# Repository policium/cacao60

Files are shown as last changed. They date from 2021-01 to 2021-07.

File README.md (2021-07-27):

# Cacao60%
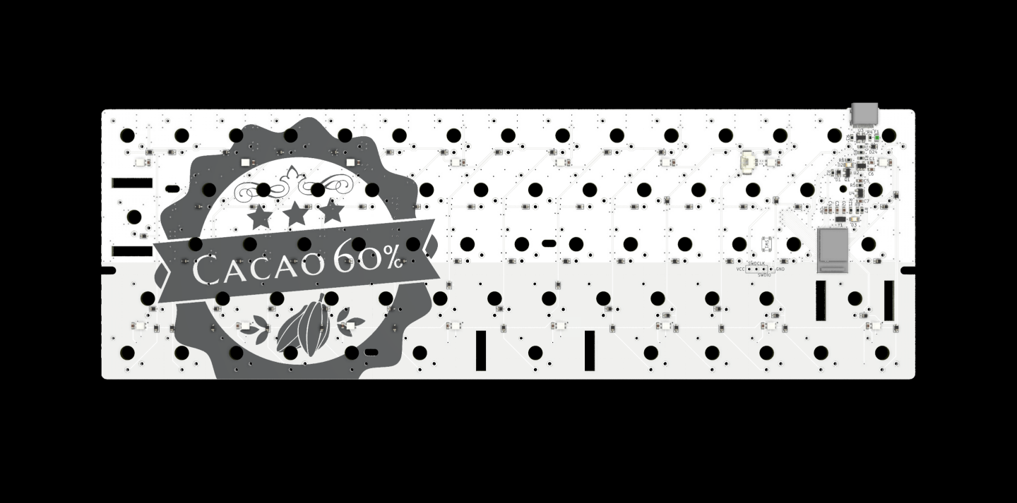
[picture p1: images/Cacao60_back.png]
  
日本語配列の無線キーボードです。

- **MCU**  
MDBT50

- **ケース**  
ロープロファイル（プレートとケースの端がツライチになるタイプ）のGH60互換ケースならフィットすると思います。

- **スイッチ**  
Kailh Choc V2専用
スタビライザーはCostar専用（3U用のワイヤーは別途準備する必要があります）

- **キーキャップ**  
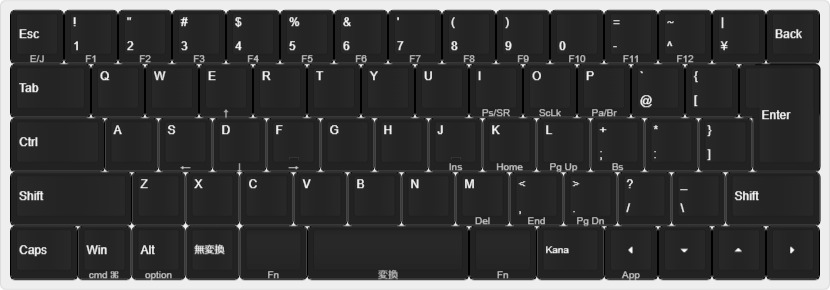
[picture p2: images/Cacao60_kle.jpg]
KLE
  
Majestouch MINILA Air用と108キー用の日本語配列ABSキーキャップを混ぜて利用

- **バッテリー**  
好きなLiPo電池を接続してください。コネクターはMolex PicoBlade PicoBlade 2Pinです。

- **バックライト、アンダーグロー**  
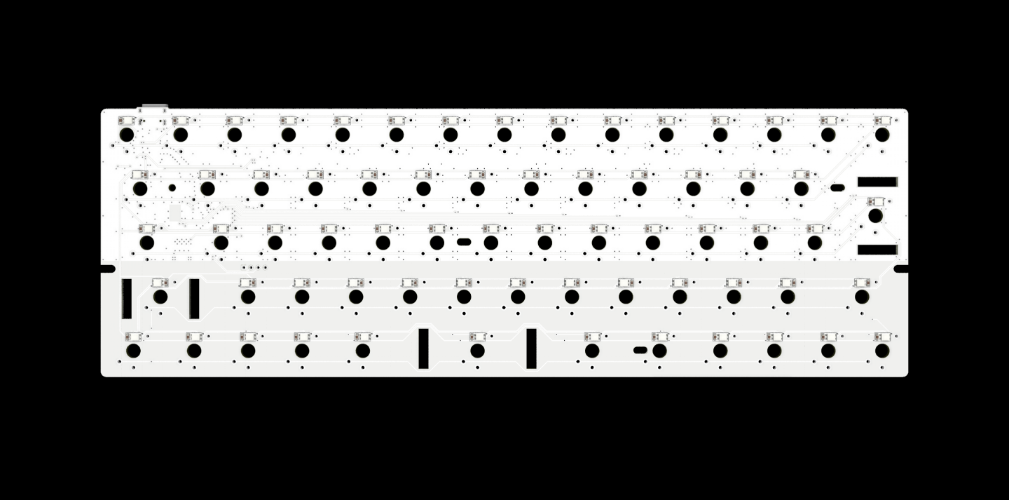
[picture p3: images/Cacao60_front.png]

SK6805 2427を用意してください

- **ファームウェア**  
ZMKやsekigon氏のQMK Firmware nRF52ブランチで動作します

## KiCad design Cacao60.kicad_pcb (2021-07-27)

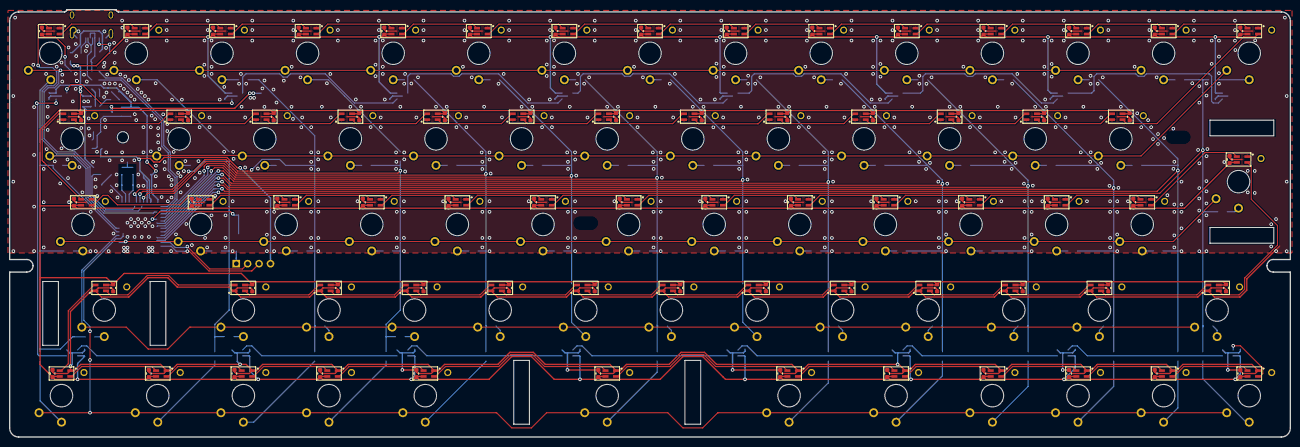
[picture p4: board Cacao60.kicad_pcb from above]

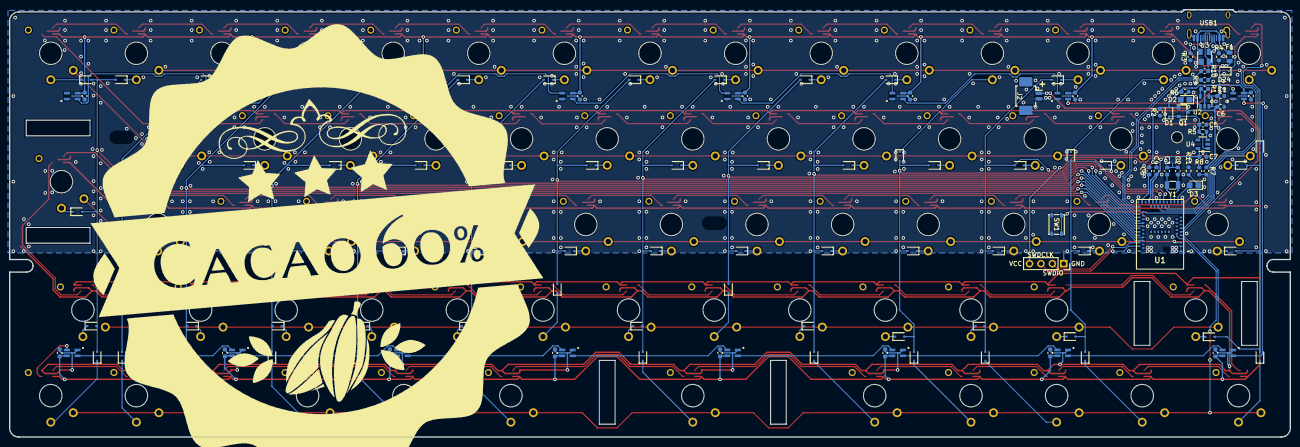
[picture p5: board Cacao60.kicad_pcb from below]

Board: 2 copper layers, 285.0 x 95.1 mm, 334 parts (133 on the bottom side), 194 nets.

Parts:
C1, C4, C5, C6, C7, C8: 10u; C_0603_1608Metric
C2, C3: 12p; C_0603_1608Metric
C9, C10, C11, C12, C13, C14, C15, C16, C17, C18, C19, C20, C21, C22, C23, C24, C25, C26, C27, C28, C29, C30, C31, C32, C33, C34, C35, C36, C37, C38, C39, C40, C41, C42, C43, C44, C45, C46, C47, C48, C49, C50, C51, C52, C53, C54, C55, C56, C57, C58, C59, C60, C61, C62, C63, C64, C65, C66, C67, C68, C69, C70, C71, C72, C73, C74, C75, C76, C77, C78, C79, C80, C81, C82, C83, C84, C85, C86, C87, C88, C89, C90, C91: 1u; C_0603_1608Metric
D1: 1N5819WS; D_SOD-323
D2: RED; LED_0805_2012Metric_Castellated
D3: BLUE; LED_0805_2012Metric_Castellated
D4, D5, D6, D7, D8, D9, D10, D11, D12, D13, D14, D15, D16, D17, D18, D19, D20, D21, D22, D23, D24, D25, D26, D27, D28, D29, D30, D31, D32, D33, D34, D35, D36, D37, D38, D39, D40, D41, D42, D43, D44, D45, D46, D47, D48, D49, D50, D51, D52, D53, D54, D55, D56, D57, D58, D59, D60, D61, D62, D63, D64, D65, D66, D67, D68, D69, D70, D71: 1N4148WS; D_SOD-323
F1: 500m; Fuse_0805_2012Metric
J1: Conn_01x04_Male; PinSocket_1x04_P2.54mm_Vertical
J2: Conn_01x02; Molex_PicoBlade_53261-0271_1x02-1MP_P1.25mm_Horizontal
K1, K6, K7, K8, K9, K10, K11, K12, K13, K14, K15, K16, K17, K18, K19, K20, K21, K22, K23, K24, K26, K27, K28, K29, K30, K31, K32, K33, K35, K36, K37, K38, K39, K40, K41, K42, K44, K45, K46, K47, K49, K50, K51, K52, K53, K54, K55, K56, K57, K58, K59, K60, K61, K62, K63, K64, K67: SW_PG1353; PG1353_1U
K2: SW_PG1353; PG1353_1.5U
K3, K66: SW_PG1353; PG1353_1.75U
K4: SW_PG1353; PG1353_2.25U
K5, K25, K43, K48: SW_PG1353; PG1353_1.25U
K34: SW_PG1353; PG1353_3U
K65: SW_PG1353; PG1353_ISOEnter
Q1: DMG2305; SOT-23
R1: 10K; R_0603_1608Metric
R2, R5: 100K; R_0603_1608Metric
R3, R4: 5.1K; R_0603_1608Metric
R6, R11: 1K; R_0603_1608Metric
R7: 715K; R_0603_1608Metric
R8: 1.8M; R_0603_1608Metric
R9, R10: 22; R_0603_1608Metric
SW1: SW_DPST_x2; SW_SPST_PTS810
U1: MDBT50Q-1MV2; MDBT50Q1MV2
U2: MCP73831-2-OT; SOT-23-5
U3: PRTR5V0U2X; SOT-143
U4: AP2112K-3.3; SOT-23-5
U5, U6, U7, U8, U9, U10, U11, U12, U13, U14, U15, U16, U17, U18, U19, U20, U21, U22, U23, U24, U25, U26, U27, U28, U29, U30, U31, U32, U33, U34, U35, U36, U37, U38, U39, U40, U41, U42, U43, U44, U45, U46, U47, U48, U49, U50, U51, U52, U53, U54, U55, U56, U57, U58, U59, U60, U61, U62, U63, U64, U65, U66, U67, U68, U69, U70, U71, U72, U73, U74, U75, U76, U77, U78, U79, U80, U81, U82, U83, U84, U85, U86, U87: SK6805; LED_SK6805-2427
USB1: HRO-TYPE-C-31-M-12
Y1: 32.768KHz; Crystal_SMD_3215-2Pin_3.2x1.5mm

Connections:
+BATT: C6.1, J2.1, Q1.3, R7.1, U2.3
/BLUE_LED: D3.2, U1.16
/COL1: D4.2, D5.2, D6.2, D7.2, D8.2, U1.6
/COL2: D9.2, D10.2, D11.2, D12.2, D13.2, U1.22
/COL3: D14.2, D15.2, D16.2, D17.2, D18.2, U1.24
/COL4: D19.2, D20.2, D21.2, D22.2, D23.2, U1.26
/COL5: D25.2, D26.2, D27.2, D28.2, D29.2, U1.37
/COL6: D30.2, D31.2, D32.2, D33.2, U1.39
/COL7: D34.2, D35.2, D36.2, D37.2, D38.2, U1.41
/COL8: D39.2, D40.2, D41.2, D42.2, U1.42
/COL9: D43.2, D44.2, D45.2, D46.2, D47.2, U1.43
/COL10: D48.2, D49.2, D50.2, D51.2, D52.2, U1.44
/COL11: D53.2, D54.2, D55.2, D56.2, D57.2, U1.46
/COL12: D58.2, D59.2, D60.2, D61.2, D62.2, U1.48
/COL13: D63.2, D64.2, D65.2, D66.2, U1.49
/COL14: D67.2, D68.2, D69.2, D70.2, D71.2, U1.50
/D+: R10.2, U1.35
/D-: R9.1, U1.34
/RESET: SW1.2, U1.40
/RGB_LED: U1.36, U5.3
/ROW1: K1.2, K6.2, K11.2, K16.2, K21.2, K26.2, K30.2, K35.2, K39.2, K44.2, K49.2, K54.2, K59.2, K63.2, U1.25
/ROW2: K2.2, K7.2, K12.2, K17.2, K22.2, K27.2, K31.2, K36.2, K40.2, K45.2, K50.2, K55.2, K60.2, K64.2, U1.8
/ROW3: K3.2, K8.2, K13.2, K18.2, K23.2, K28.2, K32.2, K37.2, K41.2, K46.2, K51.2, K56.2, K61.2, K65.2, U1.3
/ROW4: K4.2, K9.2, K14.2, K19.2, K24.2, K29.2, K33.2, K38.2, K42.2, K47.2, K52.2, K57.2, K66.2, U1.4
/ROW5: K5.2, K10.2, K15.2, K20.2, K25.2, K34.2, K43.2, K48.2, K53.2, K58.2, K62.2, K67.2, U1.5
/SWDCLK: J1.3, U1.53
/SWDIO: J1.2, U1.51
/VDIV: R7.2, R8.1, U1.21
GND: C1.2, C2.2, C3.2, C4.2, C5.2, C6.2, C7.2, C8.2, C9.2, C10.1, C11.1, C12.1, C13.1, C14.1, C15.1, C16.1, C17.1, C18.1, C19.1, C20.1, C21.1, C22.1, C23.1, C24.1, C25.1, C26.1, C27.1, C28.1, C29.1, C30.1, C31.1, C32.1, C33.1, C34.1, C35.1, C36.1, C37.1, C38.1, C39.1, C40.1, C41.1, C42.1, C43.1, C44.1, C45.1, C46.1, C47.1, C48.1, C49.1, C50.1, C51.1, C52.1, C53.1, C54.1, C55.1, C56.1, C57.1, C58.1, C59.1, C60.1, C61.1, C62.1, C63.1, C64.1, C65.1, C66.1, C67.1, C68.1, C69.1, C70.1, C71.1, C72.1, C73.1, C74.1, C75.1, C76.1, C77.1, C78.1, C79.1, C80.1, C81.1, C82.1, C83.1, C84.1, C85.1, C86.1, C87.1, C88.1, C89.1, C90.1, C91.1, J1.1, J2.2, R1.1, R2.2, R3.1, R4.1, R8.2, R11.1, SW1.1, U1.1, U1.2, U1.15, U1.33, U1.55, U2.2, U3.1, U4.2, U5.2, U6.2, U7.2, U8.2, U9.2, U10.2, U11.2, U12.2, U13.2, U14.2, U15.2, U16.2, U17.2, U18.2, U19.2, U20.2, U21.2, U22.2, U23.2, U24.2, U25.2, U26.2, U27.2, U28.2, U29.2, U30.2, U31.2, U32.2, U33.2, U34.2, U35.2, U36.2, U37.2, U38.2, U39.2, U40.2, U41.2, U42.2, U43.2, U44.2, U45.2, U46.2, U47.2, U48.2, U49.2, U50.2, U51.2, U52.2, U53.2, U54.2, U55.2, U56.2, U57.2, U58.2, U59.2, U60.2, U61.2, U62.2, U63.2, U64.2, U65.2, U66.2, U67.2, U68.2, U69.2, U70.2, U71.2, U72.2, U73.2, U74.2, U75.2, U76.2, U77.2, U78.2, U79.2, U80.2, U81.2, U82.2, U83.2, U84.2, U85.2, U86.2, U87.2, USB1.1, USB1.12, USB1.13
unnamed: C2.1, U1.17, Y1.1
unnamed: C3.1, U1.18, Y1.2
unnamed: C5.1, D1.1, Q1.2, R5.1, U4.1
unnamed: C9.1, D24.1, U5.4
unnamed: D2.1, U2.1
unnamed: D2.2, R6.1
unnamed: D3.1, R11.2
unnamed: D4.1, K1.1
unnamed: D5.1, K2.1
unnamed: D6.1, K3.1
unnamed: D7.1, K4.1
unnamed: D8.1, K5.1
unnamed: D9.1, K6.1
unnamed: D10.1, K7.1
unnamed: D11.1, K8.1
unnamed: D12.1, K9.1
unnamed: D13.1, K10.1
unnamed: D14.1, K11.1
unnamed: D15.1, K12.1
unnamed: D16.1, K13.1
unnamed: D17.1, K14.1
unnamed: D18.1, K15.1
unnamed: D19.1, K16.1
unnamed: D20.1, K17.1
unnamed: D21.1, K18.1
unnamed: D22.1, K19.1
unnamed: D23.1, K20.1
unnamed: D25.1, K21.1
unnamed: D26.1, K22.1
unnamed: D27.1, K23.1
unnamed: D28.1, K24.1
unnamed: D29.1, K25.1
unnamed: D30.1, K26.1
unnamed: D31.1, K27.1
unnamed: D32.1, K28.1
unnamed: D33.1, K29.1
unnamed: D34.1, K30.1
unnamed: D35.1, K31.1
unnamed: D36.1, K32.1
unnamed: D37.1, K33.1
unnamed: D38.1, K34.1
unnamed: D39.1, K35.1
unnamed: D40.1, K36.1
unnamed: D41.1, K37.1
unnamed: D42.1, K38.1
unnamed: D43.1, K39.1
unnamed: D44.1, K40.1
unnamed: D45.1, K41.1
unnamed: D46.1, K42.1
unnamed: D47.1, K43.1
unnamed: D48.1, K44.1
unnamed: D49.1, K45.1
unnamed: D50.1, K46.1
unnamed: D51.1, K47.1
unnamed: D52.1, K48.1
unnamed: D53.1, K49.1
unnamed: D54.1, K50.1
unnamed: D55.1, K51.1
unnamed: D56.1, K52.1
unnamed: D57.1, K53.1
unnamed: D58.1, K54.1
unnamed: D59.1, K55.1
unnamed: D60.1, K56.1
unnamed: D61.1, K57.1
unnamed: D62.1, K58.1
unnamed: D63.1, K59.1
unnamed: D64.1, K60.1
unnamed: D65.1, K61.1
unnamed: D66.1, K62.1
unnamed: D67.1, K63.1
unnamed: D68.1, K64.1
unnamed: D69.1, K65.1
unnamed: D70.1, K66.1
unnamed: D71.1, K67.1
unnamed: F1.2, U3.4, USB1.2, USB1.11
unnamed: R1.2, U2.5
unnamed: R3.2, USB1.10
unnamed: R4.2, USB1.4
unnamed: R5.2, U4.3
unnamed: R9.2, U3.3, USB1.5, USB1.7
unnamed: R10.1, U3.2, USB1.6, USB1.8
unnamed: U5.1, U6.3
unnamed: U6.1, U7.3
unnamed: U7.1, U8.3
unnamed: U8.1, U9.3
unnamed: U10.1, U11.3
unnamed: U9.1, U10.3
unnamed: U11.1, U12.3
unnamed: U12.1, U13.3
unnamed: U13.1, U14.3
unnamed: U14.1, U15.3
unnamed: U15.1, U16.3
unnamed: U16.1, U17.3
unnamed: U17.1, U18.3
unnamed: U18.1, U19.3
unnamed: U19.1, U20.3
unnamed: U20.1, U21.3
unnamed: U21.1, U22.3
unnamed: U22.1, U23.3
unnamed: U23.1, U24.3
unnamed: U24.1, U25.3
unnamed: U25.1, U26.3
unnamed: U26.1, U27.3
unnamed: U27.1, U28.3
unnamed: U28.1, U29.3
unnamed: U29.1, U30.3
unnamed: U30.1, U31.3
unnamed: U31.1, U32.3
unnamed: U32.1, U33.3
unnamed: U33.1, U34.3
unnamed: U34.1, U35.3
unnamed: U35.1, U36.3
unnamed: U36.1, U37.3
unnamed: U37.1, U38.3
unnamed: U38.1, U39.3
unnamed: U39.1, U40.3
unnamed: U40.1, U41.3
unnamed: U41.1, U42.3
unnamed: U42.1, U43.3
unnamed: U43.1, U44.3
unnamed: U44.1, U45.3
unnamed: U45.1, U46.3
unnamed: U46.1, U47.3
unnamed: U47.1, U48.3
unnamed: U48.1, U49.3
unnamed: U49.1, U50.3
unnamed: U50.1, U51.3
unnamed: U51.1, U52.3
unnamed: U52.1, U53.3
unnamed: U53.1, U54.3
unnamed: U54.1, U55.3
unnamed: U55.1, U56.3
unnamed: U56.1, U57.3
unnamed: U57.1, U58.3
unnamed: U58.1, U59.3
unnamed: U59.1, U60.3
unnamed: U60.1, U61.3
unnamed: U61.1, U62.3
unnamed: U62.1, U63.3
unnamed: U63.1, U64.3
unnamed: U64.1, U65.3
unnamed: U65.1, U66.3
unnamed: U66.1, U67.3
unnamed: U67.1, U68.3
unnamed: U68.1, U69.3
unnamed: U69.1, U70.3
unnamed: U70.1, U71.3
unnamed: U71.1, U72.3
unnamed: U72.1, U73.3
unnamed: U73.1, U74.3
unnamed: U74.1, U75.3
unnamed: U75.1, U76.3
unnamed: U76.1, U77.3
unnamed: U77.1, U78.3
unnamed: U78.1, U79.3
unnamed: U79.1, U80.3
unnamed: U80.1, U81.3
unnamed: U81.1, U82.3
unnamed: U82.1, U83.3
unnamed: U83.1, U84.3
unnamed: U84.1, U85.3
unnamed: U85.1, U86.3
unnamed: U86.1, U87.3
VBUS: C1.1, C8.1, C10.2, C11.2, C12.2, C13.2, C14.2, C15.2, C16.2, C17.2, C18.2, C19.2, C20.2, C21.2, C22.2, C23.2, C24.2, C25.2, C26.2, C27.2, C28.2, C29.2, C30.2, C31.2, C32.2, C33.2, C34.2, C35.2, C36.2, C37.2, C38.2, C39.2, C40.2, C41.2, C42.2, C43.2, C44.2, C45.2, C46.2, C47.2, C48.2, C49.2, C50.2, C51.2, C52.2, C53.2, C54.2, C55.2, C56.2, C57.2, C58.2, C59.2, C60.2, C61.2, C62.2, C63.2, C64.2, C65.2, C66.2, C67.2, C68.2, C69.2, C70.2, C71.2, C72.2, C73.2, C74.2, C75.2, C76.2, C77.2, C78.2, C79.2, C80.2, C81.2, C82.2, C83.2, C84.2, C85.2, C86.2, C87.2, C88.2, C89.2, C90.2, C91.2, D1.2, D24.2, F1.1, Q1.1, R2.1, R6.2, U1.32, U2.4, U6.4, U7.4, U8.4, U9.4, U10.4, U11.4, U12.4, U13.4, U14.4, U15.4, U16.4, U17.4, U18.4, U19.4, U20.4, U21.4, U22.4, U23.4, U24.4, U25.4, U26.4, U27.4, U28.4, U29.4, U30.4, U31.4, U32.4, U33.4, U34.4, U35.4, U36.4, U37.4, U38.4, U39.4, U40.4, U41.4, U42.4, U43.4, U44.4, U45.4, U46.4, U47.4, U48.4, U49.4, U50.4, U51.4, U52.4, U53.4, U54.4, U55.4, U56.4, U57.4, U58.4, U59.4, U60.4, U61.4, U62.4, U63.4, U64.4, U65.4, U66.4, U67.4, U68.4, U69.4, U70.4, U71.4, U72.4, U73.4, U74.4, U75.4, U76.4, U77.4, U78.4, U79.4, U80.4, U81.4, U82.4, U83.4, U84.4, U85.4, U86.4, U87.4
VCC: C4.1, C7.1, J1.4, U1.28, U1.30, U4.5
